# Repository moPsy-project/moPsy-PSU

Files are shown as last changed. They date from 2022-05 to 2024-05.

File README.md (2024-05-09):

# moPsy PSU

> This reposiory contains schematics and PCB files, as well as
> documentation, for the moPsy Power Supply Unit (PSU).

Please make sure you also have the
[moPsy-KiCad-resources](https://github.com/moPsy-project/moPsy-KiCad-resources)
available when opening these projects.

## Status of the Design

I am still in the design process and this is not the final revision.
During the several design stages I have come up with ideas for a simpler
design.
However, at this stage, it would be more expensive to start over than to
build what is available and learn from the iteration. 

More information will appear here as I update the project.

## Contents

This repository is a collection of several projects making up my PSU:

* [BusBoard 1](moPsy_BusBoard_1)
* [BusBoard 2](moPsy_BusBoard_2)
* [Regulator +5V](moPsy_Regulator_5Vpos_BusGate)

PCBs that have been ordered and are in production:

* [Rectifier Board](#11)
* [Regulator 12V positive](#12)
* [Regulator 12V negative](#13)
* [Capacitor Charger](#9)

Parts that are WIP:

* [Capacitor Board](#10)

## License

OSHW Banner
CC BY-SA Banner

This work is licensed under a [Creative Commons Attribution-ShareAlike 4.0 International License](http://creativecommons.org/licenses/by-sa/4.0/).

Exception: The moPsy logo is © 2021-2024 Stefan Haun

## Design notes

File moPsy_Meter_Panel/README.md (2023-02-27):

# moPsy PSU: Meter Panel

> Simple Panel to host Voltage and Current meters

This panel hosts a 25V voltmeter and a 5A current meter to show the load on the incoming power rails, right after transformer and rectifier.

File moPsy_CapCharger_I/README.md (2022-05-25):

# moPsy PSU: Cap Charger 1

> Charge controller for the load capacitors

The big capacitors want to be charged slowly.

This is a first and very dump version of a charge controller.
Just wait a while until the current limit is lifted and power is
supplied to the Synthesizer.

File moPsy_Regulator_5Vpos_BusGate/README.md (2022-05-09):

# moPsy PSU: 5V Regulator

> 5V Regulator meant to be used in the case

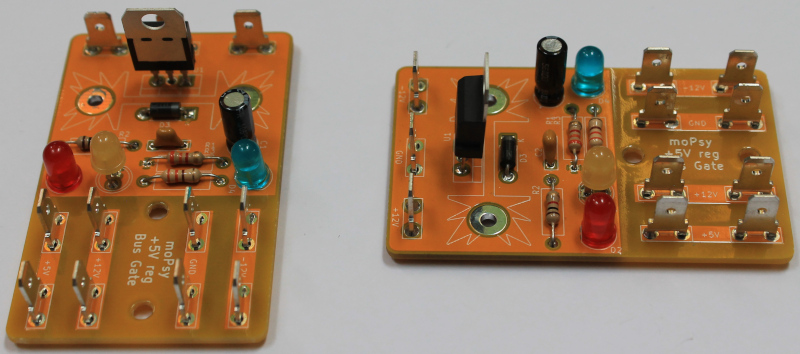
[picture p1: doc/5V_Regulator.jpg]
Two perspecives of the soldered 5V regulator


## License

See [License in the main README](../README.md).

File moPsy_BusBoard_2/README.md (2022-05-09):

# moPsy PSU: BusBoard 2

> BusBoard that can be used in two directions

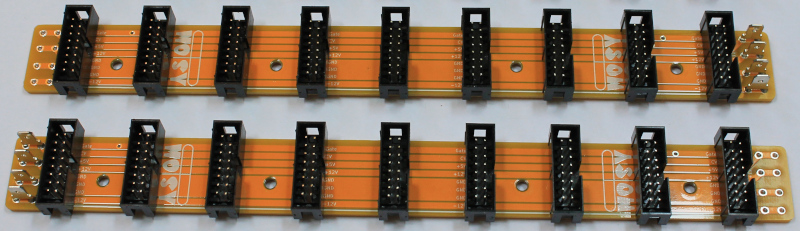
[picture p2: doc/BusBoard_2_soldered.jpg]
Picture of two soldered bus boards


## License

See [License in the main README](../README.md).

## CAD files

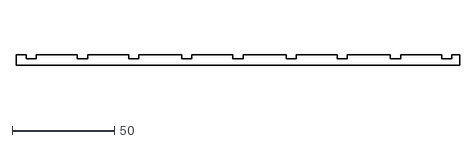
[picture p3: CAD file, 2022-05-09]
moPsy_BusBoard_2/BusDistance-BusBufferSketch.dxf
217.0 x 5.00

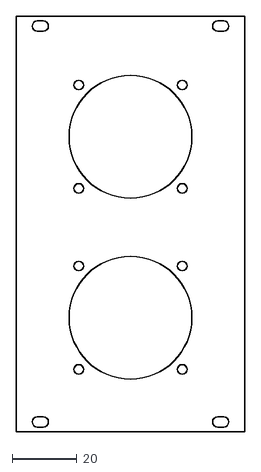
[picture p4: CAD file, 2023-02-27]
moPsy_Meter_Panel/meter-panel-outline.dxf
70.8 x 128.5

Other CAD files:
moPsy_BusBoard_2/BusDistance.FCStd
moPsy_Meter_Panel/meter-panel.FCStd

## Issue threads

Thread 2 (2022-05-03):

Add EDA files to the repository

penguineer, 2022-05-03:
- [x] bus board
- [x] capacitor board
- [x] capacitor charger board
- [x] rectifier board
- [x] 12V pos regulator board
- [x] 12V neg regulator board
- [x] 5V pos regulator board

Closed 2022-05-09.

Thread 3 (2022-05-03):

Route the missing PCBs

penguineer, 2022-05-03:
- [x] rectifier board
- [x] 12V neg regulator board
- [ ] 12V pos regulator board

Closed 2022-05-25.

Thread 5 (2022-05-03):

Design front plate for voltage/current meters

penguineer, 2022-05-03:

penguineer, 2023-04-17:
Resolved in #20

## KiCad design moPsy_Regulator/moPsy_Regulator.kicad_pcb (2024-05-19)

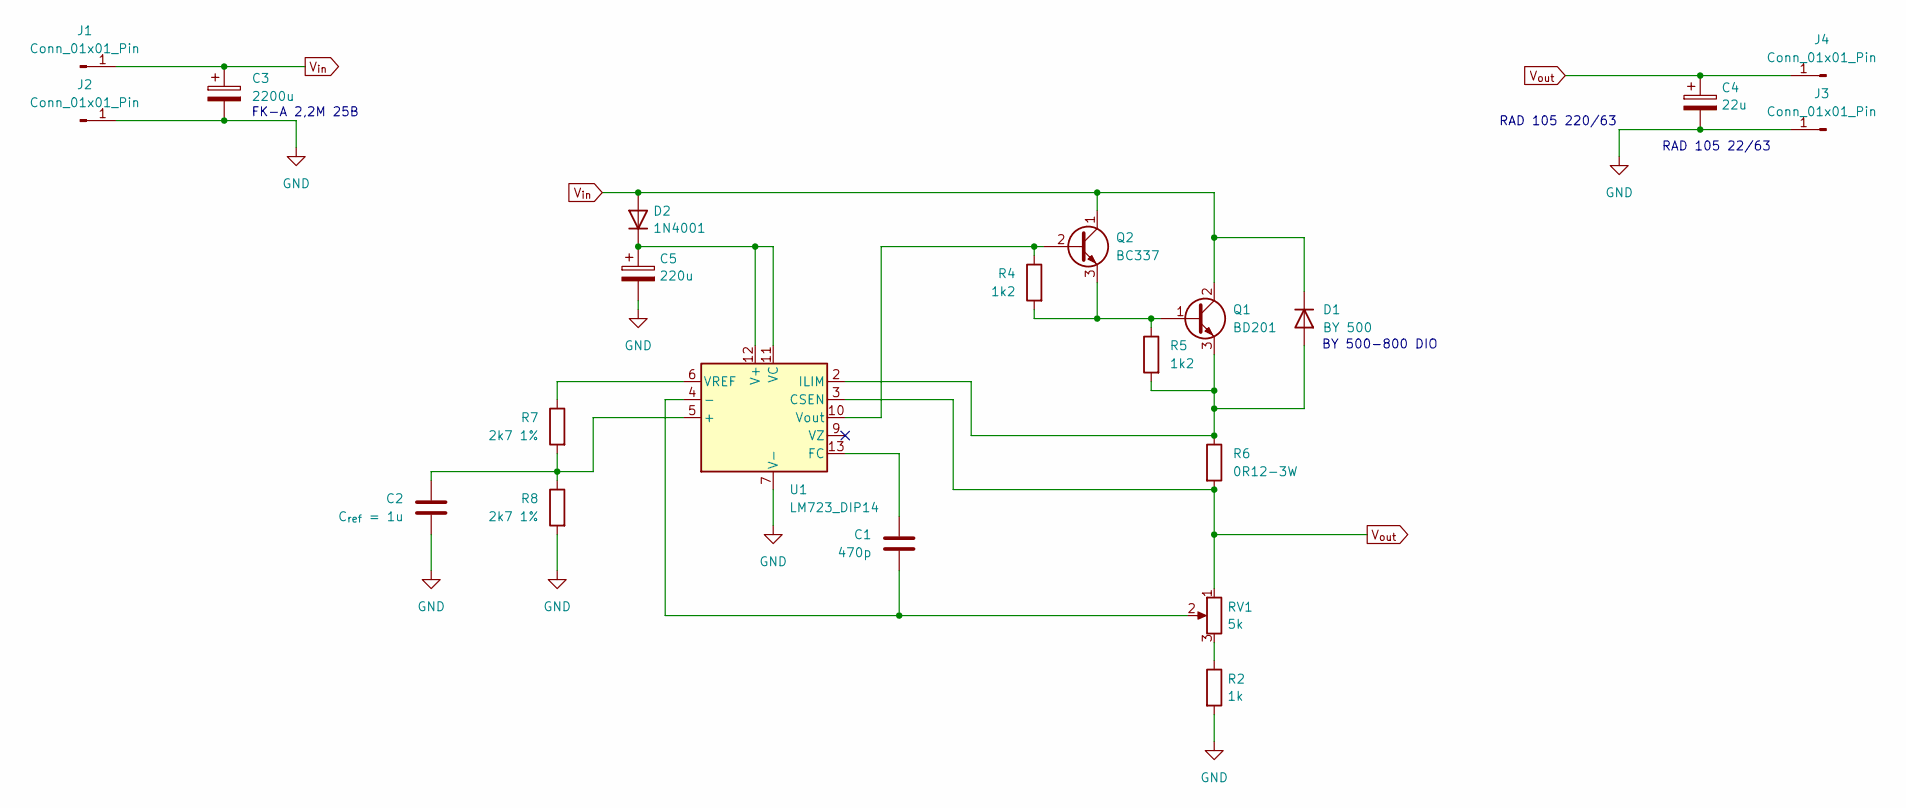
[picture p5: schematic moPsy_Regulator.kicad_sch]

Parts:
C1: 470p; C_Disc_D4.3mm_W1.9mm_P5.00mm
C2: C_{ref} = 1u; C_Disc_D4.3mm_W1.9mm_P5.00mm
C3: 2200u; CP_Radial_D16.0mm_P7.50mm
C4: 22u; CP_Radial_D6.3mm_P2.50mm
C5: 220u; CP_Radial_D10.0mm_P5.00mm
D1: BY 500; D_DO-201_P12.70mm_Horizontal
D2: 1N4001; D_DO-41_SOD81_P7.62mm_Horizontal
J1, J2, J3, J4: Conn_01x01_Pin; Connector FS-P475
Q1: BD201; TO-220-3_Vertical
Q2: BC337; TO-92_HandSolder
R2: 1k; R_Axial_DIN0207_L6.3mm_D2.5mm_P7.62mm_Horizontal
R4, R5: 1k2; R_Axial_DIN0207_L6.3mm_D2.5mm_P7.62mm_Horizontal
R6: 0R12-3W; R_Axial_DIN0614_L14.3mm_D5.7mm_P15.24mm_Horizontal
R7, R8: 2k7 1%; R_Axial_DIN0207_L6.3mm_D2.5mm_P7.62mm_Horizontal
RV1: 5k; Potentiometer_Piher_PT-10-V10_Vertical
U1: LM723_DIP14; DIP-14_W7.62mm_LongPads

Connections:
GND: C2.2, C3.2, C4.2, C5.2, J2.1, J3.1, R2.2, R8.2, U1.7 (V-)
unnamed: D1.2 (A), Q1.3 (E), R5.2, R6.1, U1.2 (ILIM)
unnamed: C5.1, D2.1 (K), U1.11 (VC), U1.12 (V+)
unnamed: Q1.1 (B), Q2.3 (E), R4.2, R5.1
unnamed: Q2.2 (B), R4.1, U1.10 (Vout)
unnamed: R2.1, RV1.3
unnamed: C2.1, R7.2, R8.1, U1.5 (+)
unnamed: C1.2, RV1.2, U1.4 (-)
unnamed: C1.1, U1.13 (FC)
unnamed: R7.1, U1.6 (VREF)
V_{in}: C3.1, D1.1 (K), D2.2 (A), J1.1, Q1.2 (C), Q2.1 (C)
V_{out}: C4.1, J4.1, R6.2, RV1.1, U1.3 (CSEN)

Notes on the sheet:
BY 500-800 DIO
RAD 105 22/63
RAD 105 220/63
FK-A 2,2M 25B

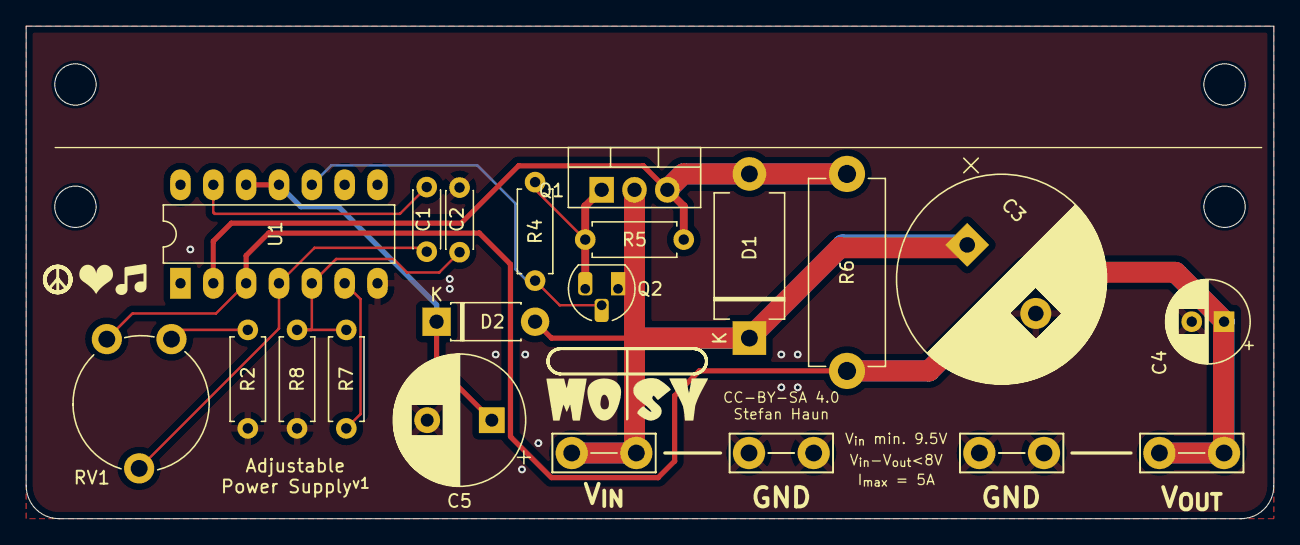
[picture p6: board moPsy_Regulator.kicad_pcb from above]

Board: 2 copper layers, 96.5 x 38.1 mm, 25 parts (0 on the bottom side), 12 nets.

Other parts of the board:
REF1, REF1#2, REF2, REF2#2: MountingHole_3.2mm_M3

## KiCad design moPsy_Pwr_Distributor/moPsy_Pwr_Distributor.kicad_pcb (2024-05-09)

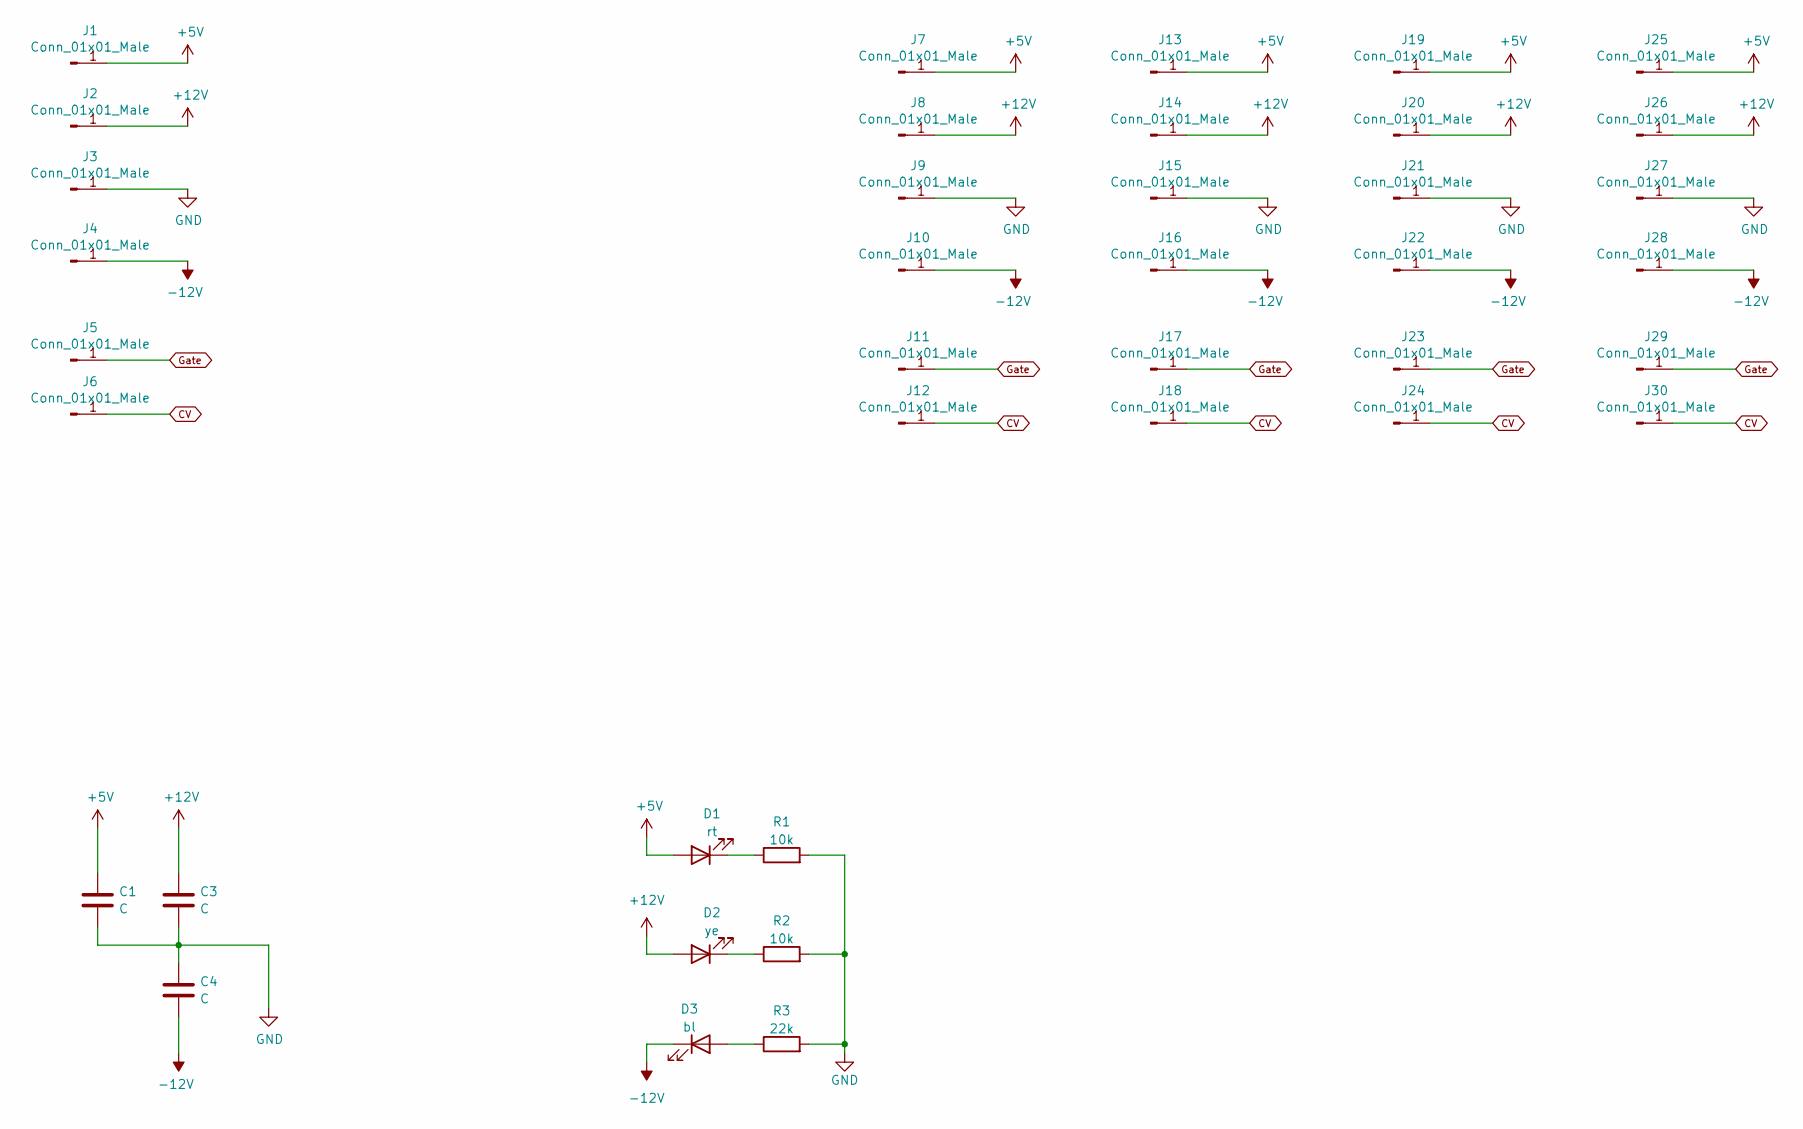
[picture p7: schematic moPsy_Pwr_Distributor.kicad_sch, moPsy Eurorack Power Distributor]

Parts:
C1, C3, C4: C; C_Rect_L7.0mm_W2.5mm_P5.00mm
D1: rt; LED_D3.0mm
D2: ye; LED_D3.0mm
D3: bl; LED_D3.0mm
J1, J2, J3, J4, J7, J8, J9, J10, J13, J14, J15, J16, J19, J20, J21, J22, J25, J26, J27, J28: Conn_01x01_Male; Connector FS-P475
J5, J6, J11, J12, J17, J18, J23, J24, J29, J30: Conn_01x01_Male; Pin_D0.9mm_L10.0mm_W2.4mm_FlatFork
R1, R2: 10k; R_Axial_DIN0207_L6.3mm_D2.5mm_P7.62mm_Horizontal
R3: 22k; R_Axial_DIN0207_L6.3mm_D2.5mm_P7.62mm_Horizontal

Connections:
+5V: C1.1, D1.2 (A), J1.1, J7.1, J13.1, J19.1, J25.1
+12V: C3.1, D2.2 (A), J2.1, J8.1, J14.1, J20.1, J26.1
-12V: C4.2, D3.1 (K), J4.1, J10.1, J16.1, J22.1, J28.1
CV: J6.1, J12.1, J18.1, J24.1, J30.1
GND: C1.2, C3.2, C4.1, J3.1, J9.1, J15.1, J21.1, J27.1, R1.2, R2.2, R3.2
Gate: J5.1, J11.1, J17.1, J23.1, J29.1
unnamed: D1.1 (K), R1.1
unnamed: D2.1 (K), R2.1
unnamed: D3.2 (A), R3.1

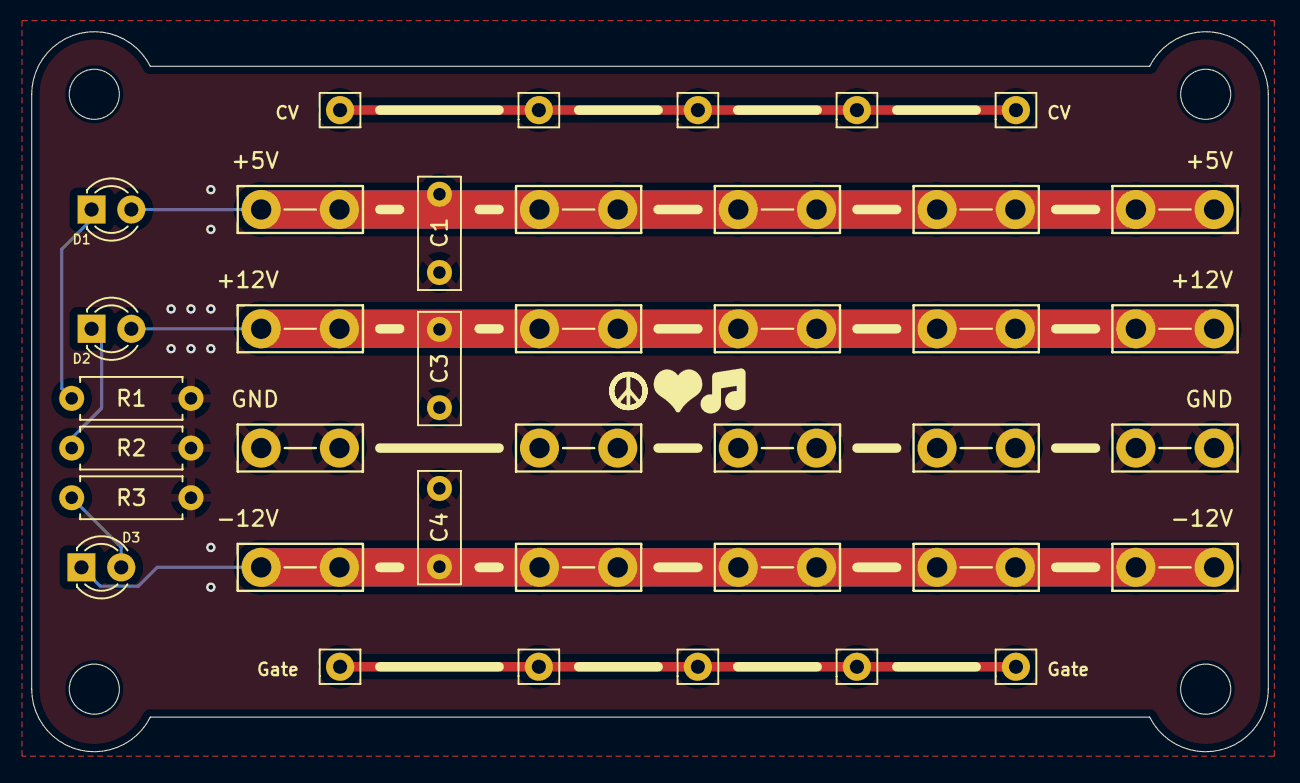
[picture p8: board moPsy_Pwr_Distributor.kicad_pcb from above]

Board: 2 copper layers, 79.0 x 46.0 mm, 39 parts (0 on the bottom side), 9 nets.

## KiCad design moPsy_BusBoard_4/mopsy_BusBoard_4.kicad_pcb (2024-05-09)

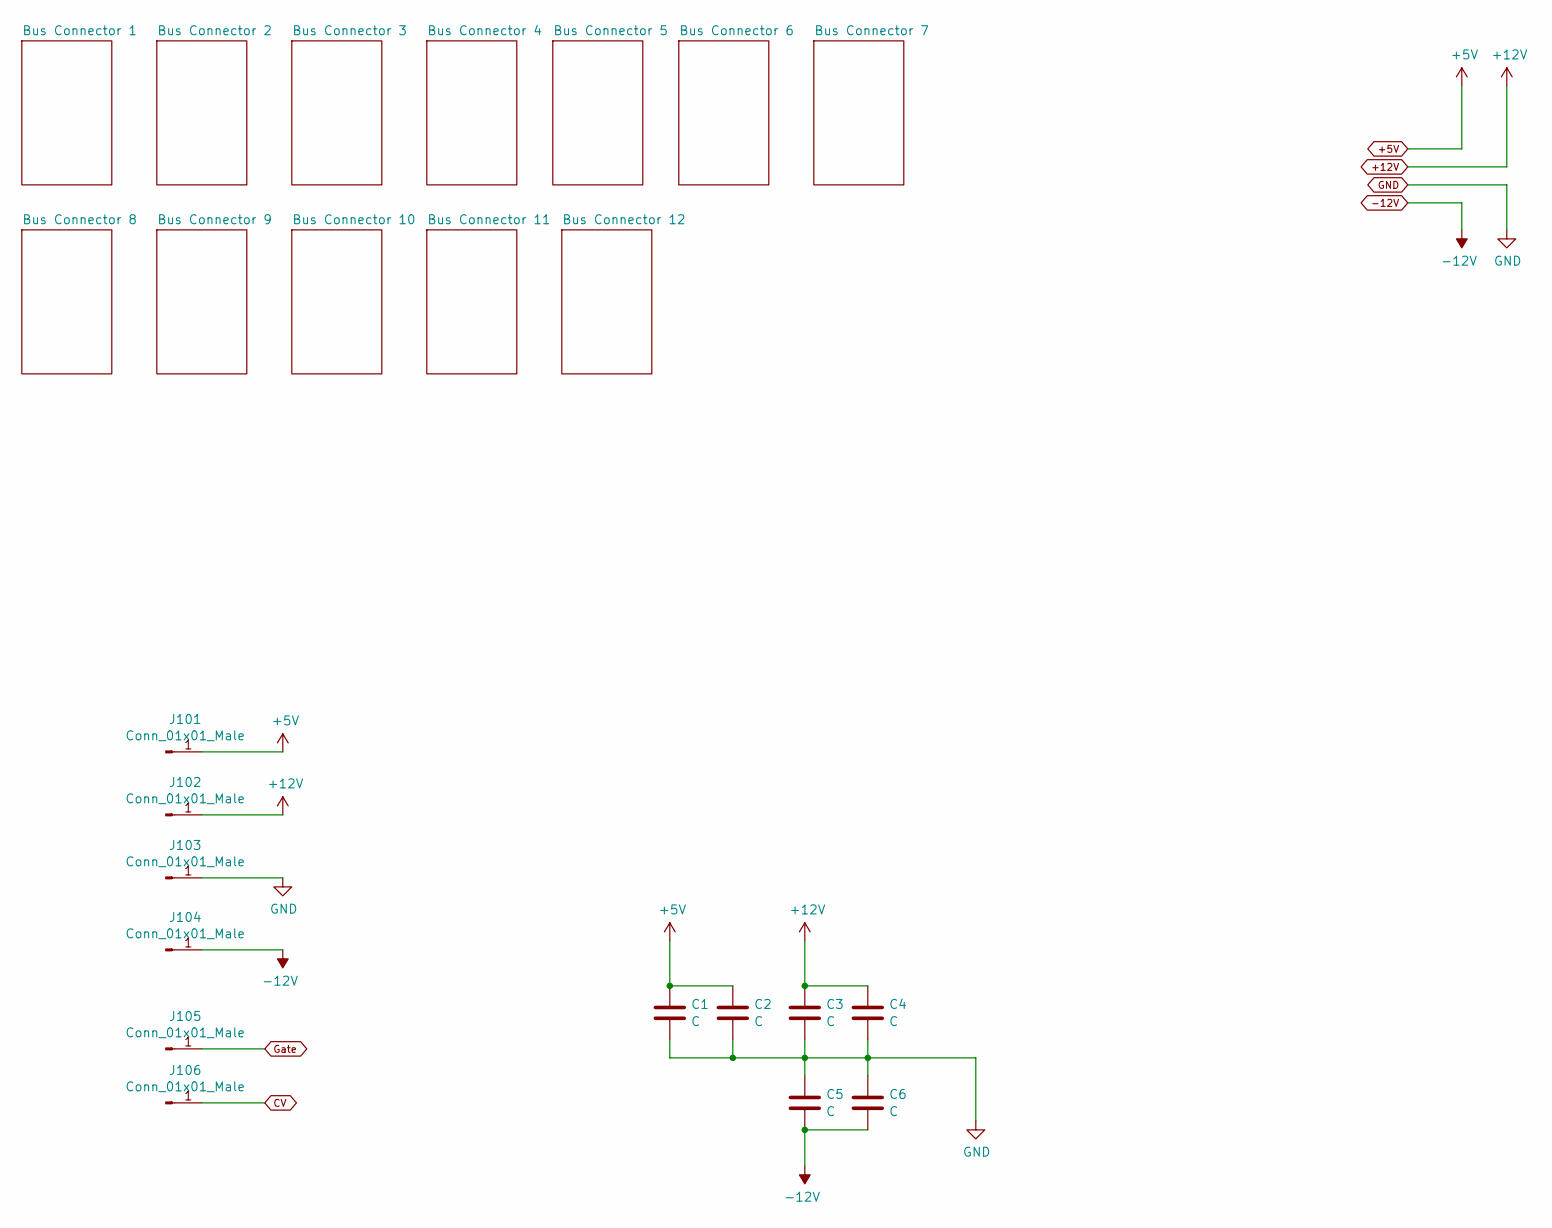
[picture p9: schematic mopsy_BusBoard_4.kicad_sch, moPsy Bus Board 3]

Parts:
C1, C2, C3, C4, C5, C6: C; C_Rect_L7.0mm_W2.5mm_P5.00mm
J101, J102, J103, J104: Conn_01x01_Male; Connector FS-P475
J105, J106: Conn_01x01_Male; Pin_D0.9mm_L10.0mm_W2.4mm_FlatFork

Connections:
+5V: C1.1, C2.1, J101.1; also elsewhere on the board
+12V: C3.1, C4.1, J102.1; also elsewhere on the board
-12V: C5.2, C6.2, J104.1; also elsewhere on the board
CV: J106.1; also elsewhere on the board
GND: C1.2, C2.2, C3.2, C4.2, C5.1, C6.1, J103.1; also elsewhere on the board
Gate: J105.1; also elsewhere on the board

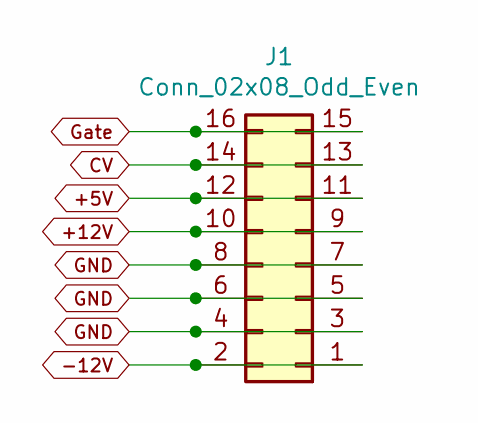
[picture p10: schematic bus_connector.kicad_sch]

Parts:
J1: Conn_02x08_Odd_Even; PinHeader_2x08_P2.54mm_Vertical

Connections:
+5V: J1.11, J1.12; also elsewhere on the board
+12V: J1.9, J1.10; also elsewhere on the board
-12V: J1.1, J1.2; also elsewhere on the board
CV: J1.13, J1.14; also elsewhere on the board
GND: J1.3, J1.4, J1.5, J1.6, J1.7, J1.8; also elsewhere on the board
Gate: J1.15, J1.16; also elsewhere on the board

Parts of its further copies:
J2, J3, J4, J5, J6, J7, J8, J9, J10, J11, J12: Conn_02x08_Odd_Even; PinHeader_2x08_P2.54mm_Vertical

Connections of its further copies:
+5V: J2.11, J2.12, J3.11, J3.12, J4.11, J4.12, J5.11, J5.12, J6.11, J6.12, J7.11, J7.12, J8.11, J8.12, J9.11, J9.12, J10.11, J10.12, J11.11, J11.12, J12.11, J12.12; also elsewhere on the board
+12V: J2.9, J2.10, J3.9, J3.10, J4.9, J4.10, J5.9, J5.10, J6.9, J6.10, J7.9, J7.10, J8.9, J8.10, J9.9, J9.10, J10.9, J10.10, J11.9, J11.10, J12.9, J12.10; also elsewhere on the board
-12V: J2.1, J2.2, J3.1, J3.2, J4.1, J4.2, J5.1, J5.2, J6.1, J6.2, J7.1, J7.2, J8.1, J8.2, J9.1, J9.2, J10.1, J10.2, J11.1, J11.2, J12.1, J12.2; also elsewhere on the board
CV: J2.13, J2.14, J3.13, J3.14, J4.13, J4.14, J5.13, J5.14, J6.13, J6.14, J7.13, J7.14, J8.13, J8.14, J9.13, J9.14, J10.13, J10.14, J11.13, J11.14, J12.13, J12.14; also elsewhere on the board
GND: J2.3, J2.4, J2.5, J2.6, J2.7, J2.8, J3.3, J3.4, J3.5, J3.6, J3.7, J3.8, J4.3, J4.4, J4.5, J4.6, J4.7, J4.8, J5.3, J5.4, J5.5, J5.6, J5.7, J5.8, J6.3, J6.4, J6.5, J6.6, J6.7, J6.8, J7.3, J7.4, J7.5, J7.6, J7.7, J7.8, J8.3, J8.4, J8.5, J8.6, J8.7, J8.8, J9.3, J9.4, J9.5, J9.6, J9.7, J9.8, J10.3, J10.4, J10.5, J10.6, J10.7, J10.8, J11.3, J11.4, J11.5, J11.6, J11.7, J11.8, J12.3, J12.4, J12.5, J12.6, J12.7, J12.8; also elsewhere on the board
Gate: J2.15, J2.16, J3.15, J3.16, J4.15, J4.16, J5.15, J5.16, J6.15, J6.16, J7.15, J7.16, J8.15, J8.16, J9.15, J9.16, J10.15, J10.16, J11.15, J11.16, J12.15, J12.16; also elsewhere on the board

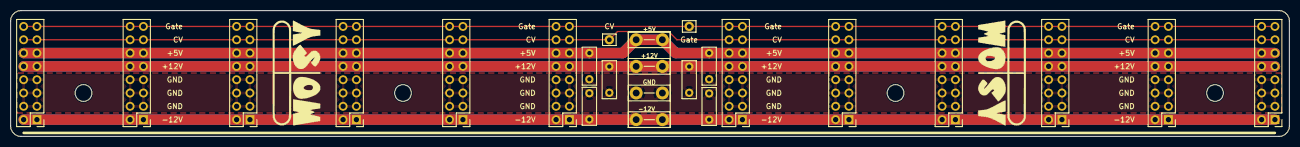
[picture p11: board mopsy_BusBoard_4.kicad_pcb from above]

Board: 2 copper layers, 244.0 x 24.0 mm, 26 parts (0 on the bottom side), 6 nets.

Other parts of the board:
Ref**: Val**; moPsy_logo_kicad_20x09_FSilk
Ref**#2: Val**; moPsy_logo_kicad_20x09_FSilk

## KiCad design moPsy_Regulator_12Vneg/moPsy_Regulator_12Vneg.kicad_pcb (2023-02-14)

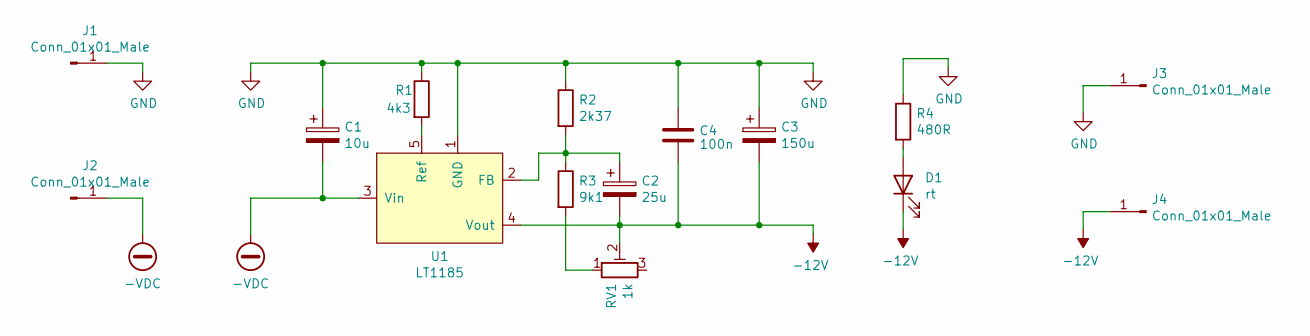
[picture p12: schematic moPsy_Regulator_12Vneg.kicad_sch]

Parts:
C1: 10u; CP_Radial_D5.0mm_P2.50mm
C2: 25u; CP_Radial_D5.0mm_P2.00mm
C3: 150u; CP_Radial_D8.0mm_P3.50mm
C4: 100n; C_Rect_L7.0mm_W2.0mm_P5.00mm
D1: rt; LED_D5.0mm
J1, J2, J3, J4: Conn_01x01_Male; Connector FS-P475
R1: 4k3; R_Axial_DIN0207_L6.3mm_D2.5mm_P7.62mm_Horizontal
R2: 2k37; R_Axial_DIN0207_L6.3mm_D2.5mm_P7.62mm_Horizontal
R3: 9k1; R_Axial_DIN0207_L6.3mm_D2.5mm_P7.62mm_Horizontal
R4: 480R; R_Axial_DIN0207_L6.3mm_D2.5mm_P2.54mm_Vertical
RV1: 1k; Suntan 3296 Trim Pot
U1: LT1185; TO-220-5_P3.4x3.7mm_StaggerOdd_Lead3.8mm_Vertical

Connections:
-12V: C2.2, C3.2, C4.2, D1.1 (K), J4.1, RV1.2, U1.4 (Vout)
-VDC: C1.2, J2.1, U1.3 (Vin)
GND: C1.1, C3.1, C4.1, J1.1, J3.1, R1.1, R2.1, R4.1, U1.1 (GND)
unnamed: D1.2 (A), R4.2
unnamed: R3.2, RV1.1
unnamed: C2.1, R2.2, R3.1, U1.2 (FB)
unnamed: R1.2, U1.5 (Ref)

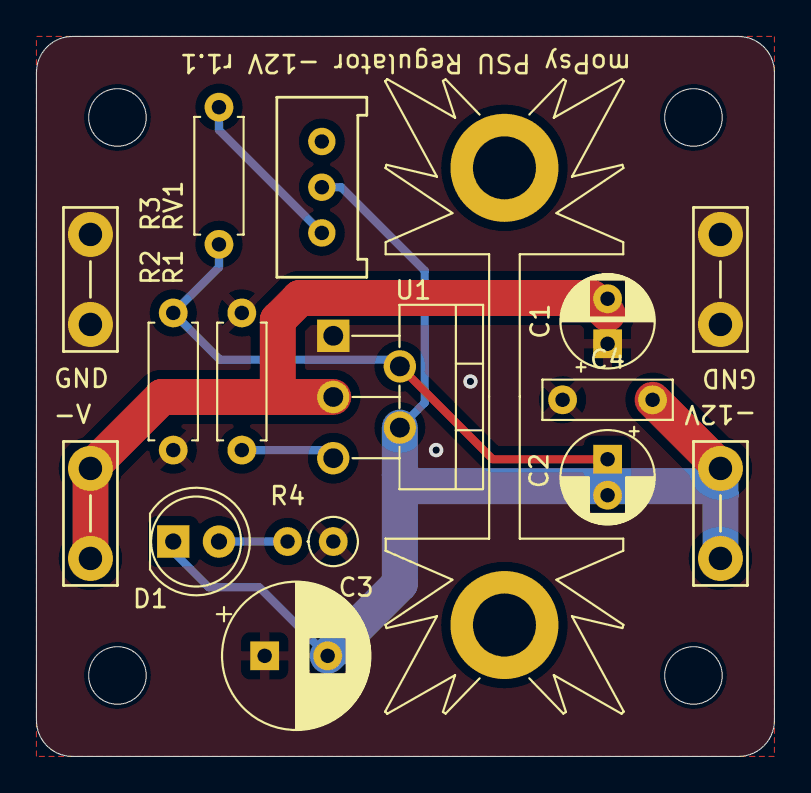
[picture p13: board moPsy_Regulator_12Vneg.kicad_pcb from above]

Board: 2 copper layers, 41.0 x 40.0 mm, 16 parts (1 on the bottom side), 7 nets.

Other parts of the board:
Ref**: Val**; moPsy_logo_kicad_20x09_FSilk

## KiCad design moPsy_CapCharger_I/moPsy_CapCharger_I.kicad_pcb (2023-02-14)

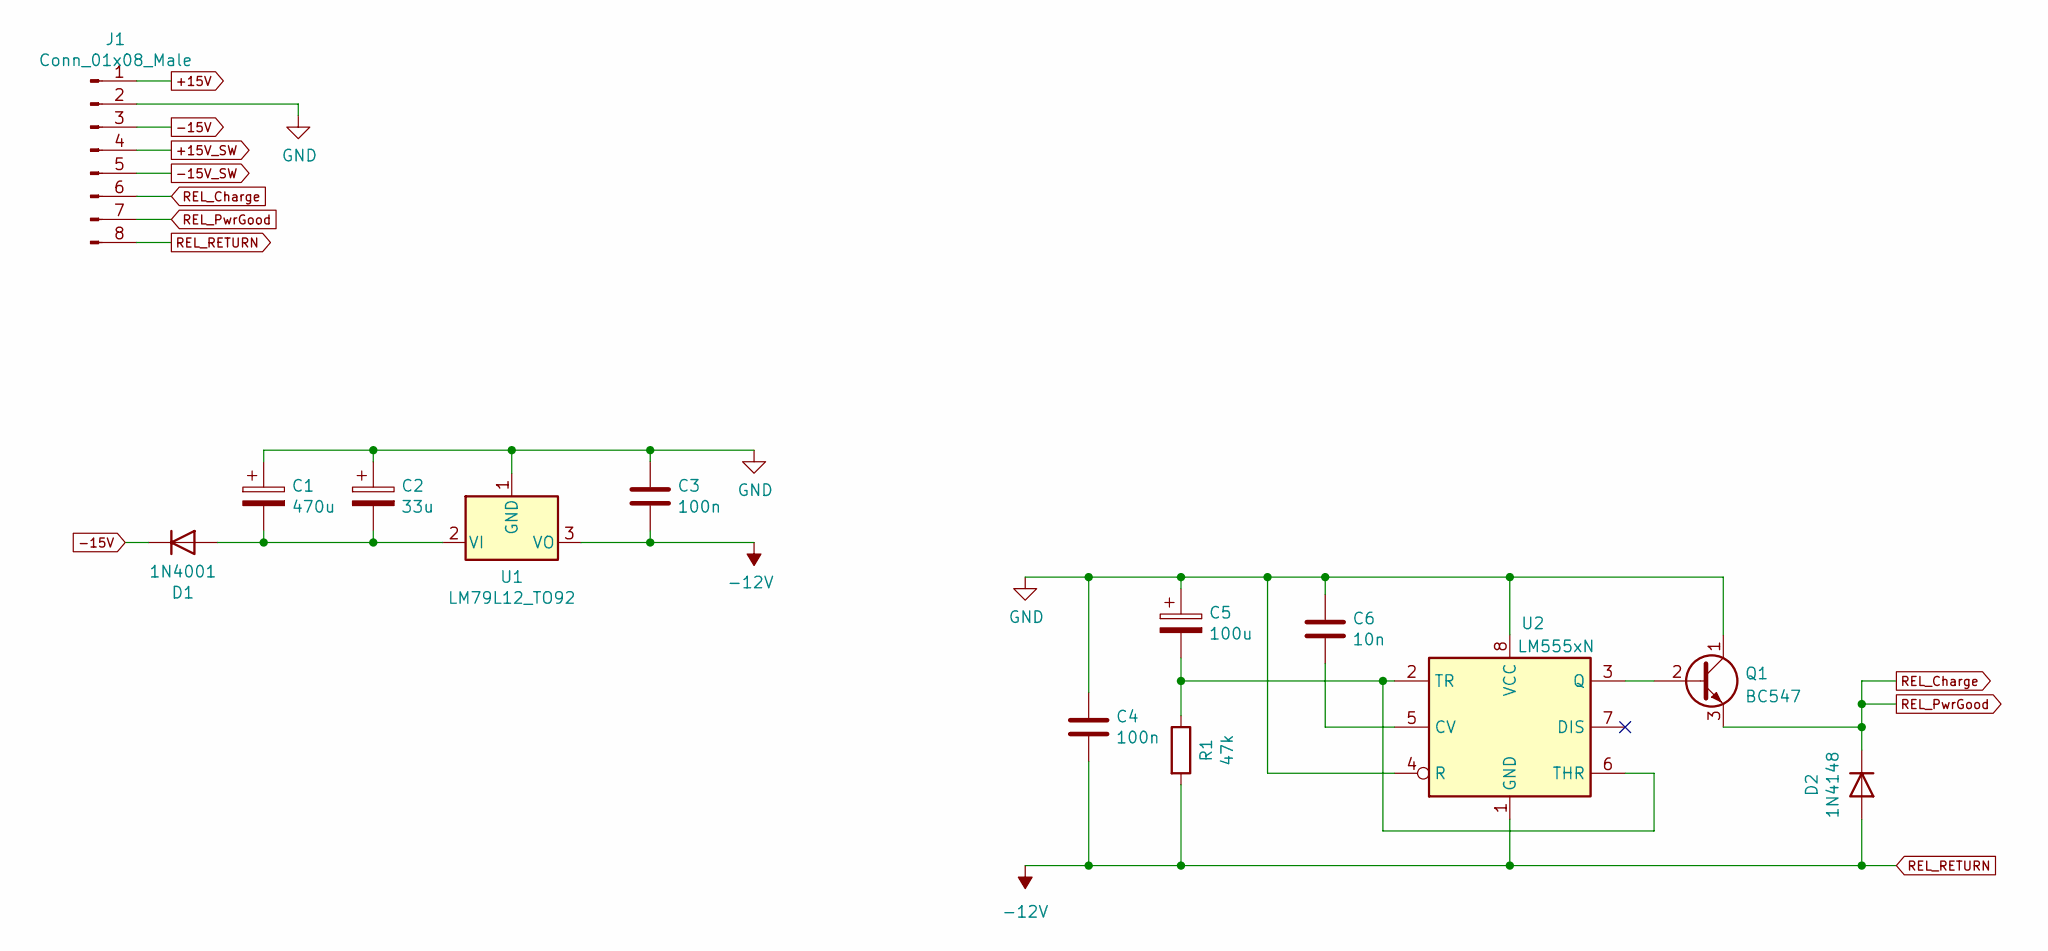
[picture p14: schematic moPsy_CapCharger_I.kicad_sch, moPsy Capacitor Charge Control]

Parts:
C1: 470u; C_Axial_L19.0mm_D9.5mm_P25.00mm_Horizontal
C2: 33u; CP_Radial_D8.0mm_P3.50mm
C3, C4: 100n; C_Rect_L7.0mm_W2.5mm_P5.00mm
C5: 100u; CP_Radial_D8.0mm_P3.50mm
C6: 10n; C_Rect_L7.0mm_W2.5mm_P5.00mm
D1: 1N4001; D_DO-41_SOD81_P7.62mm_Horizontal
D2: 1N4148; D_DO-41_SOD81_P7.62mm_Horizontal
J1: Conn_01x08_Male; PinHeader_1x08_P2.54mm_Horizontal
Q1: BC547; TO-92_Inline
R1: 47k; R_Axial_DIN0207_L6.3mm_D2.5mm_P7.62mm_Horizontal
U1: LM79L12_TO92; TO-92_Inline
U2: LM555xN; DIP-8_W7.62mm

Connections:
+15V: J1.1
+15V_SW: J1.4
-15V: D1.1 (K), J1.3
-15V_SW: J1.5
GND: C1.1, C2.1, C3.1, C4.1, C5.1, C6.1, J1.2, Q1.1 (C), U1.1 (GND), U2.4 (R), U2.8 (VCC)
unnamed: C1.2, C2.2, D1.2 (A), U1.2 (VI)
unnamed: C5.2, R1.1, U2.2 (TR), U2.6 (THR)
unnamed: C6.2, U2.5 (CV)
unnamed: Q1.2 (B), U2.3 (Q)
REL_Charge: D2.1 (K), J1.6, J1.7, Q1.3 (E)
REL_RETURN: C3.2, C4.2, D2.2 (A), J1.8, R1.2, U1.3 (VO), U2.1 (GND)

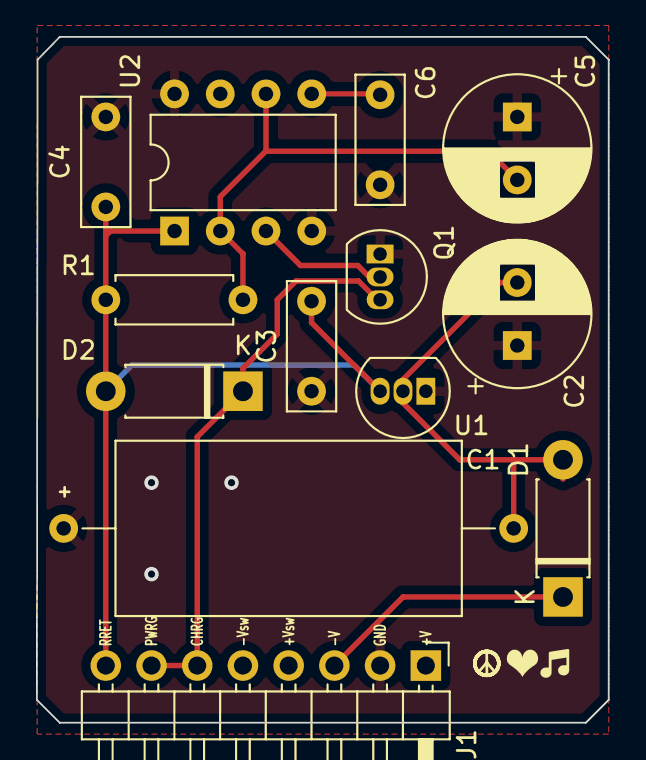
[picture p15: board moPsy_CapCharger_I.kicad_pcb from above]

Board: 2 copper layers, 31.8 x 38.1 mm, 13 parts (0 on the bottom side), 8 nets.

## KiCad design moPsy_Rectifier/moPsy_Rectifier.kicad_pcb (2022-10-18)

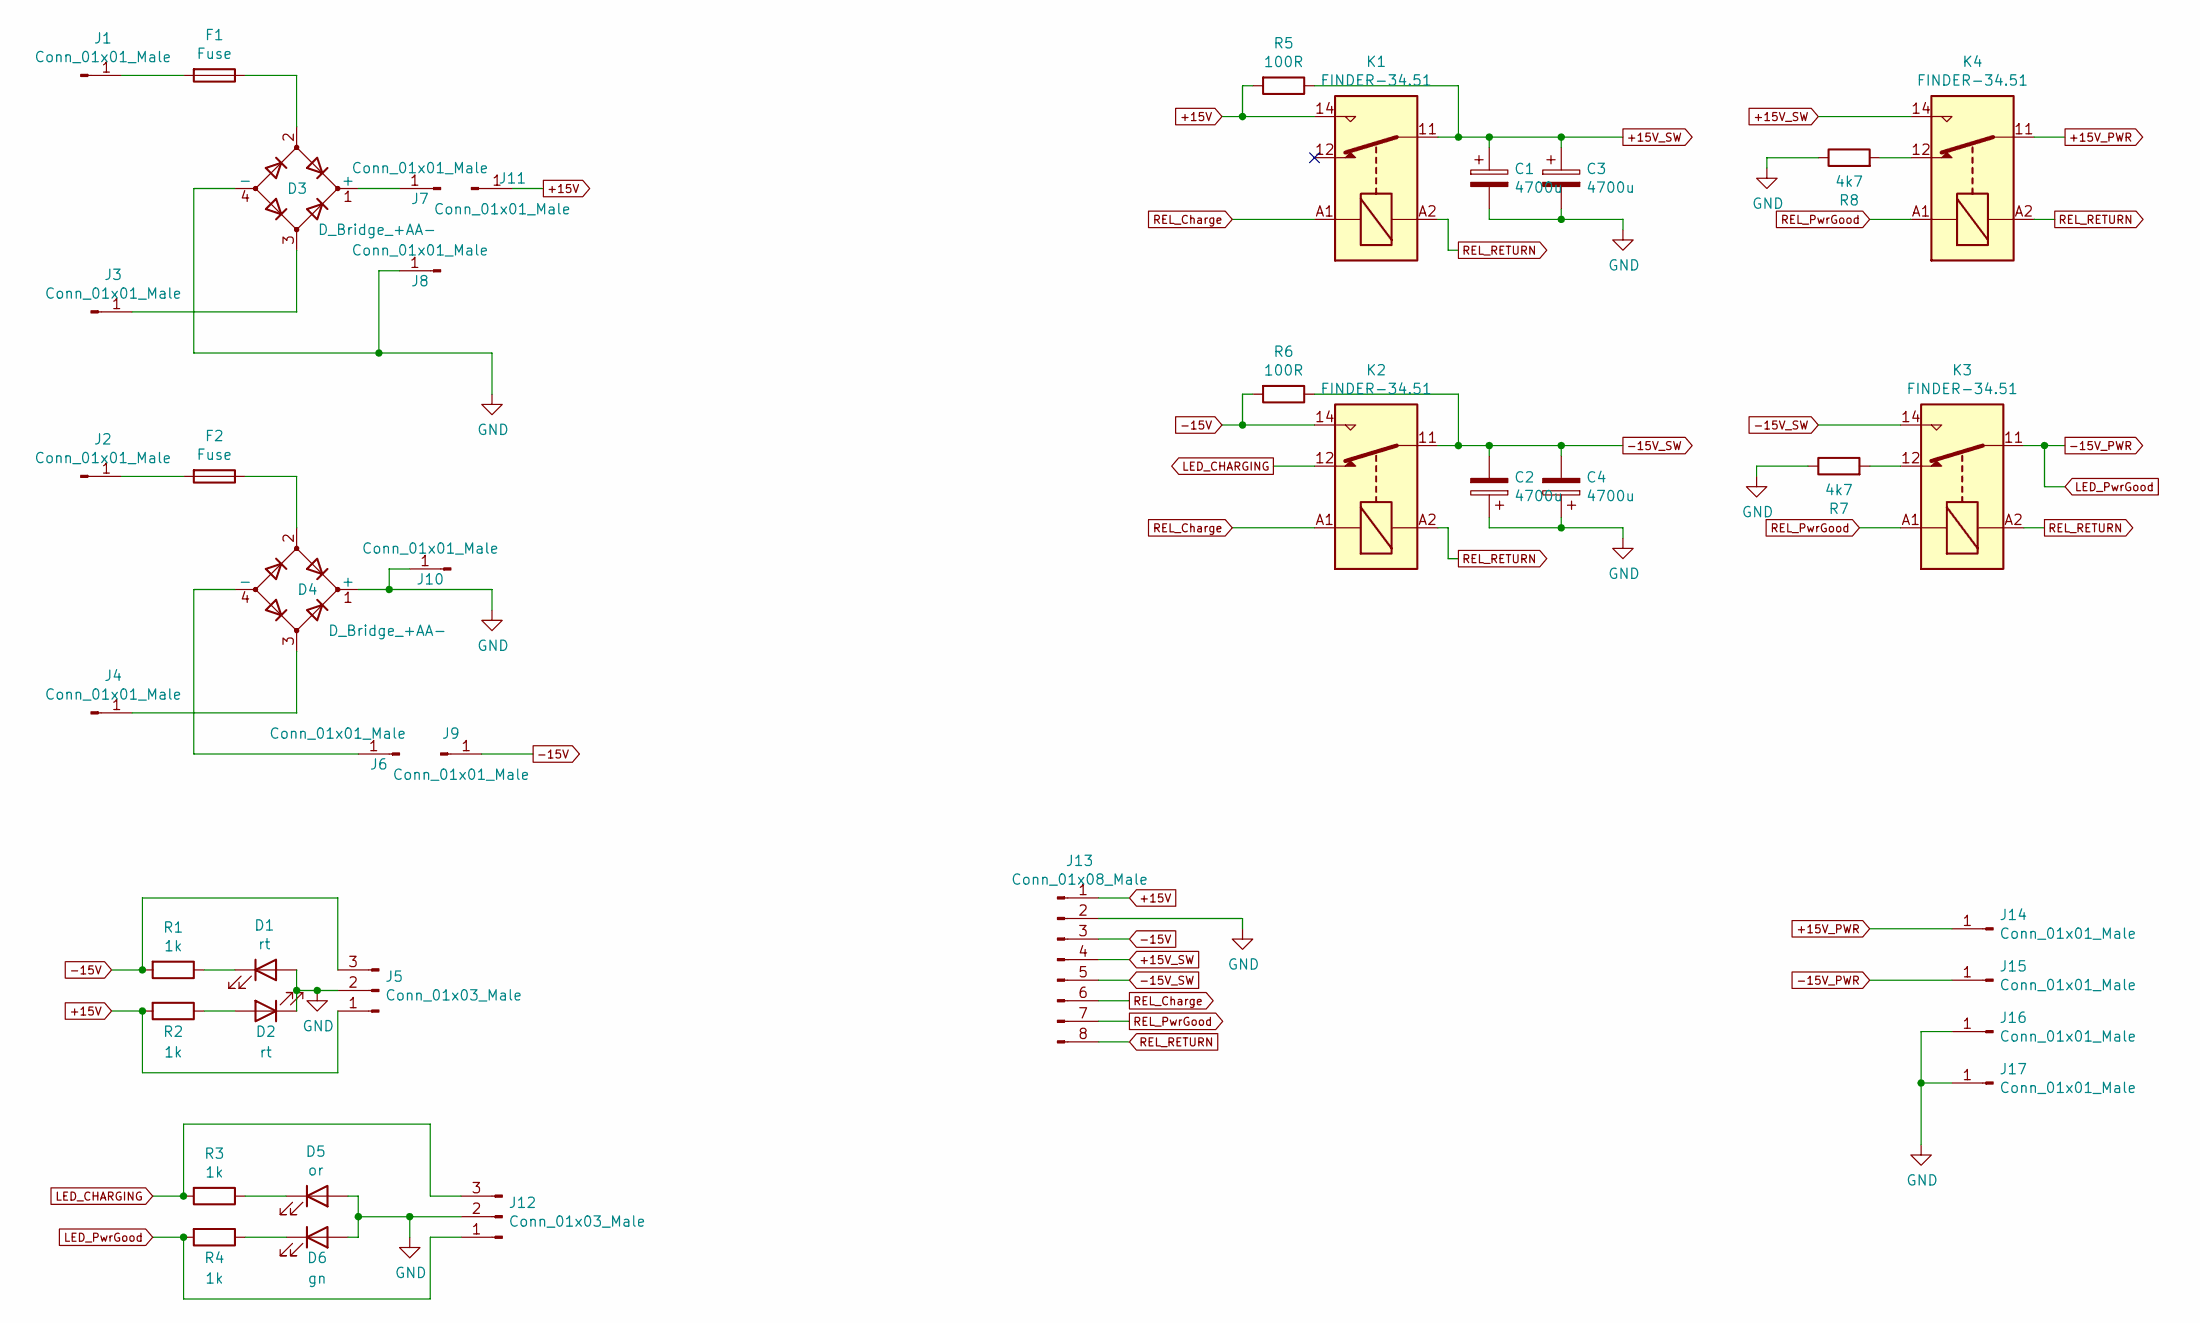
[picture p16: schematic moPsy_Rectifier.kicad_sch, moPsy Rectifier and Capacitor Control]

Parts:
C1, C2, C3, C4: 4700u; CP_Radial_D22.0mm_P10.00mm_SnapIn
D1, D2: rt; LED_D5.0mm
D3, D4: D_Bridge_+AA-; Diode_Bridge_32.0x5.6x17.0mm_P10.0mm_P7.5mm
D5: or; LED_D5.0mm
D6: gn; LED_D5.0mm
F1, F2: Fuse; Fuseholder_Cylinder-5x20mm_Stelvio-Kontek_PTF78_Horizontal_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
J1, J2, J3, J4, J6, J7, J8, J9, J10, J11, J14, J15, J16, J17: Conn_01x01_Male; Connector FS-P475
J5, J12: Conn_01x03_Male; PinHeader_1x03_P2.54mm_Vertical
J13: Conn_01x08_Male; PinSocket_1x08_P2.54mm_Vertical
K1, K2, K3, K4: FINDER-34.51; HF41FC
R1, R2, R3, R4: 1k; R_Axial_DIN0309_L9.0mm_D3.2mm_P12.70mm_Horizontal
R5, R6: 100R; R_Axial_DIN0614_L14.3mm_D5.7mm_P5.08mm_Vertical
R7, R8: 4k7; R_Axial_DIN0309_L9.0mm_D3.2mm_P12.70mm_Horizontal

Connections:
+15V: J5.1, J11.1, J13.1, K1.14, R2.2, R5.2
+15V_PWR: J14.1, K4.11
+15V_SW: C1.1, C3.1, J13.4, K1.11, K4.14, R5.1
-15V: J5.3, J9.1, J13.3, K2.14, R1.2, R6.2
-15V_PWR: J12.1, J15.1, K3.11, R4.2
-15V_SW: C2.2, C4.2, J13.5, K2.11, K3.14, R6.1
GND: C1.2, C2.1, C3.2, C4.1, D1.2 (A), D2.1 (K), D3.4 (-), D4.1 (+), D5.2 (A), D6.2 (A), J5.2, J8.1, J10.1, J12.2, J13.2, J16.1, J17.1, R7.1, R8.1
LED_CHARGING: J12.3, K2.12, R3.2
unnamed: D1.1 (K), R1.1
unnamed: D2.2 (A), R2.1
unnamed: D3.1 (+), J7.1
unnamed: D3.2, F1.1
unnamed: D3.3, J3.1
unnamed: D4.2, F2.1
unnamed: D4.3, J4.1
unnamed: D4.4 (-), J6.1
unnamed: D5.1 (K), R3.1
unnamed: D6.1 (K), R4.1
unnamed: F1.2, J1.1
unnamed: F2.2, J2.1
unnamed: K3.12, R7.2
unnamed: K4.12, R8.2
REL_Charge: J13.6, K1.A1, K2.A1
REL_PwrGood: J13.7, K3.A1, K4.A1
REL_RETURN: J13.8, K1.A2, K2.A2, K3.A2, K4.A2


Board: 2 copper layers, 134.6 x 72.4 mm, 42 parts (0 on the bottom side), 25 nets.

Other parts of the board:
Ref**: Val**; moPsy_logo_kicad_20x09_FSilk

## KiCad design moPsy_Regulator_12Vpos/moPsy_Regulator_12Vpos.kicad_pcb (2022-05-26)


Board: 2 copper layers, 41.0 x 40.0 mm, 14 parts (1 on the bottom side), 5 nets.

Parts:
C1: 10u; CP_Radial_D5.0mm_P2.50mm
C2: 25u; CP_Radial_D5.0mm_P2.00mm
C3: 150u; CP_Radial_D8.0mm_P3.50mm
D2: 1N4002; D_DO-41_SOD81_P7.62mm_Horizontal
D3: rt; LED_D5.0mm
J1, J2, J3, J4: Conn_01x01_Male; Connector FS-P475
R1: 100R; R_Axial_DIN0207_L6.3mm_D2.5mm_P7.62mm_Horizontal
R2: 480R; R_Axial_DIN0207_L6.3mm_D2.5mm_P7.62mm_Horizontal
RV1: 1k; Suntan 3296 Trim Pot
Ref**: Val**; moPsy_logo_kicad_20x09_FSilk
U1: LT1084-ADJ; TO-220-3_Vertical

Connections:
+12V: C3.1, D2.2, D3.2, J3.1, R1.1, U1.2
+VDC: C1.1, D2.1, J1.1, U1.3
GND: C1.2, C2.2, C3.2, J2.1, J4.1, R2.2, RV1.2
unnamed: C2.1, R1.2, RV1.1, U1.1
unnamed: D3.1, R2.1

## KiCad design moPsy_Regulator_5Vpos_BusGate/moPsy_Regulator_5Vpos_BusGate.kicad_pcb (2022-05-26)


Board: 2 copper layers, 64.0 x 40.0 mm, 21 parts (0 on the bottom side), 7 nets.

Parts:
C1: 10u; CP_Radial_D5.0mm_P2.00mm
C2: 100n; C_Rect_L7.0mm_W2.0mm_P5.00mm
D1: ye; LED_D5.0mm
D2: rd; LED_D5.0mm
D3: 1N4001; D_DO-41_SOD81_P7.62mm_Horizontal
D4: bl; LED_D5.0mm
J1, J2, J3, J5, J7, J9, J11, J13, J15, J18, J19: Conn_01x01_Male; Connector FS-P475
R1, R2, R3: 520; R_Axial_DIN0309_L9.0mm_D3.2mm_P12.70mm_Horizontal
U1: L7805; TO-220-3_Vertical

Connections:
+5V: C2.1, D3.2, J9.1, J11.1, R2.1, U1.3
+12V: C1.1, D3.1, J1.1, J5.1, J7.1, R1.1, U1.1
-12V: D4.1, J3.1, J13.1, J15.1
GND: C1.2, C2.2, D1.1, D2.1, J2.1, J18.1, J19.1, R3.1, U1.2
unnamed: D1.2, R1.2
unnamed: D2.2, R2.2
unnamed: D4.2, R3.2

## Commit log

2022-05-09 Commit current progress of BusBoard 1
    [moPsy_BusBoard.kicad_pcb, moPsy_BusBoard.sch]
2022-05-09 Add current progress for BusBoard 2
    [mopsy_BusBoard_2.kicad_pcb, mopsy_BusBoard_2.sch]
2022-05-09 Add Gerber files as sent to manufacturer on 2021-07-01
2022-05-09 Bus distance helper CNC shape
    [BusDistance-BusBufferSketch.dxf, BusDistance.FCStd]
2022-05-09 Add gitignore for the 5V Regulator
2022-05-09 Add README for 5V Regulator
2022-05-09 Add Gerber files as sent to the manufacturer on 2021-07-01
2022-05-09 Add current progress on 5V Regulator
    [moPsy_Regulator_5Vpos_BusGate.kicad_pcb, moPsy_Regulator_5Vpos_BusGate.sch]
2022-05-09 Add 5V regulator to list in README
2022-05-09 Add gitignore for the Cap Charger
2022-05-09 Add README for the Cap Charger
2022-05-09 Add current progress for the Cap Charger
    [moPsy_CapCharger_I.kicad_pcb, moPsy_CapCharger_I.sch]
2022-05-09 Add link to moPsy-KiCad-resources
2022-05-09 Fix link to KiCad resources project
2022-05-24 Add gitignore for Regulator 12V positive
2022-05-24 Add data sheet for the LT1085 regulator
2022-05-24 Add current progress for Regulator 12V positive
    [moPsy_Regulator_12Vpos.kicad_pcb, moPsy_Regulator_12Vpos.kicad_sch]
2022-05-24 Add gitignore for Regulator 12V negative
2022-05-24 Add data sheet for the LT1185 regulator
2022-05-24 Add current progress for Regulator 12V negative
    [moPsy_Regulator_12Vneg.kicad_pcb, moPsy_Regulator_12Vneg.kicad_sch]
2022-05-24 Add current progress for Rectifier
    [moPsy_Rectifier.kicad_pcb, moPsy_Rectifier.kicad_sch]
2022-05-24 PCB Layout
    [moPsy_Rectifier.kicad_pcb, moPsy_Rectifier.kicad_sch]
2022-05-25 Finishing and Roundes Corners
    [moPsy_Rectifier.kicad_pcb]
2022-05-25 Convert to KiCAD 6
    [moPsy_CapCharger_I.kicad_pcb, moPsy_CapCharger_I.kicad_sch, moPsy_CapCharger_I.sch]
2022-05-25 Changes/additions when creating Gerber file
    [moPsy_Regulator_12Vpos.kicad_pcb]
2022-05-25 Changes made when creating Gerber files
    [moPsy_Regulator_12Vneg.kicad_pcb]
2022-05-25 Changes made when creating Gerber file
    [moPsy_Rectifier.kicad_pcb]
2022-05-25 Update PCB status
2022-05-26 Add OSHW logo to 5Vpos BusGate PCB
    [moPsy_Regulator_5Vpos_BusGate.kicad_pcb]
2022-05-26 Add OSHW logo to Regulator 12V pos PCB
    [moPsy_Regulator_12Vpos.kicad_pcb]
2022-05-26 Add OSHW logo to Regulator 12V neg PCB
    [moPsy_Regulator_12Vneg.kicad_pcb]
2022-05-26 Add OSHW logo to Rectifier PCB
    [moPsy_Rectifier.kicad_pcb]
2022-05-26 Add OSHW logo to Cap Charger PCB
    [moPsy_CapCharger_I.kicad_pcb]
2022-05-26 Add OSHW logo to BusBoard 2 PCB
    [mopsy_BusBoard_2.kicad_pcb]
2022-07-10 Remove obsolete files for 5Vpos BusGate
    [moPsy_Regulator_5Vpos_BusGate.sch]
2022-10-18 Fix direction of V+ Pwr indicator LED
    [moPsy_Rectifier.kicad_pcb, moPsy_Rectifier.kicad_sch]
2023-02-12 Add 100n cap to the -12V regulator output for stability
    [moPsy_Regulator_12Vneg.kicad_sch]
2023-02-12 Add missing files for the bus gate
    Somehow these have been forgotten when updating the Kicad files...
    [moPsy_Regulator_5Vpos_BusGate.kicad_sch]
2023-02-12 Fix the Cap Charger circuit
    The previous circuit did the wrong thing. This one is based
    on https://elektro.turanis.de/html/prj248/index.html and has
    the correct behaviour.
    In the end, an RC element and a trigger are needed.
    [moPsy_CapCharger_I.kicad_sch]
2023-02-12 Add a charge capacitor
    [moPsy_CapCharger_I.kicad_sch]
2023-02-12 Design a new PCB for the cap charger
    [moPsy_CapCharger_I.kicad_pcb, moPsy_CapCharger_I.kicad_sch]
2023-02-13 Add fix for delay circuit
    [moPsy_CapCharger_I.kicad_pcb, moPsy_CapCharger_I.kicad_sch]
2023-02-14 Change revision number to 1.1
    While it has been a complete re-design, it is effectively still the feature
    set from version 1, so only change the minor version.
    [moPsy_CapCharger_I.kicad_pcb]
2023-02-14 Put cap for -12V regulator on PCB
    [moPsy_Regulator_12Vneg.kicad_pcb, moPsy_Regulator_12Vneg.kicad_sch]
2023-02-14 Advance board revision to 1.1
    [moPsy_Regulator_12Vneg.kicad_pcb]
2023-02-27 :sparkles: Create outline for the meter panel
    The used meters are:
    * [PM 2-25V](http://www.reichelt.de/index.html?ARTICLE=14732) - Drehspul-Messwerk, 25 V, 60x46 mm
    * [PM 2-5A](http://www.reichelt.de/index.html?ARTICLE=14743) - Drehspul-Messwerk, 5 A, 60x46 mm
    [meter-panel.FCStd]
2023-02-27 :art: Change mounting hole to 3mm
    It seems (from experimentation) that the mounting screws are not es
    exact a fit as the sketches suggest. Increasing the holes to 3mm
    compensates for the inaccuracy.
    [meter-panel.FCStd]
2023-02-27 :bento: Add DXF export for the panel outline
    [meter-panel-outline.dxf]
2024-05-09 Add gitignore for Bus Board 3
2024-05-09 Add KiCad files for Bus Board variant 3
    [bus_connector.kicad_sch, mopsy_BusBoard_3.kicad_pcb, mopsy_BusBoard_3.kicad_sch]
2024-05-09 Add gitignore for bus board 4
2024-05-09 Add KiCad files for Bus Board 4
    [bus_connector.kicad_sch, mopsy_BusBoard_4.kicad_pcb, mopsy_BusBoard_4.kicad_sch]
2024-05-09 Add gitignore for Power Distributor
2024-05-09 Add KiCad files for the Power Distributor
    [moPsy_Pwr_Distributor.kicad_pcb, moPsy_Pwr_Distributor.kicad_sch]
2024-05-15 Add gitignore for the regulator project
2024-05-15 Add KiCad project files for the regulator project
    [moPsy_Regulator.kicad_pcb, moPsy_Regulator.kicad_sch]
2024-05-15 Schematic for the regulator
    [moPsy_Regulator.kicad_sch]
2024-05-16 First draft of the PCB
    [moPsy_Regulator.kicad_pcb, moPsy_Regulator.kicad_sch]
2024-05-16 Small fixes and Greographic Renumeration
    [moPsy_Regulator.kicad_pcb, moPsy_Regulator.kicad_sch]
2024-05-16 Improve the voltage selection and layout
    [moPsy_Regulator.kicad_pcb, moPsy_Regulator.kicad_sch]
2024-05-16 Geographical Reannotation and some minor fixes
    [moPsy_Regulator.kicad_pcb, moPsy_Regulator.kicad_sch]
2024-05-17 Improve the circuit
    [moPsy_Regulator.kicad_pcb, moPsy_Regulator.kicad_sch]
2024-05-19 Set hole positions and board outline
    [moPsy_Regulator.kicad_pcb]

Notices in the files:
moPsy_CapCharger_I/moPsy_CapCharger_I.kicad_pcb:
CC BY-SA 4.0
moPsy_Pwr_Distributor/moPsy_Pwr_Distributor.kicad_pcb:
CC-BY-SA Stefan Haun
